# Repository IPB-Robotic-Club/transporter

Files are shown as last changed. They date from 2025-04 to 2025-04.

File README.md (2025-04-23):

# Transporter Robot  
This project features a two-wheeled transporter robot manually controlled via a PlayStation 3 wireless joystick over Bluetooth. Driven by an ESP32 running Arduino code, the robot includes a motorized gripper that can open, close, and move vertically to pick up and move objects.

## Transporter Robot Using ESP32 and PS3 Joystick

### 📘 Introduction  
The Transporter Robot project aims to build a two-wheeled robot capable of manually transporting objects in a controlled environment using a Bluetooth-connected PlayStation 3 joystick. The robot is powered by an ESP32 microcontroller running Arduino code. It features a dual-servo gripper system—one for lifting and one for gripping—and DC motors for directional movement.

### ⚙️ Key Features  
- **Manual Control:** Operated via a PS3 joystick connected through Bluetooth using MAC address pairing.  
- **Motorized Gripper System:**  
  - **MG90S Servo:** Controls the open/close movement of the gripper.  
  - **MG996R Servo:** Controls the vertical movement of the gripper for lifting.  
- **Two-Wheel Drive:** Two DC motors for movement—forward, backward, turning left/right.  
- **Stable Power Supply:** 3S LiPo battery regulated by LM2596 to 5V for safe component operation.  
- **Compact & Modular Design:** Frame and gripper parts are custom-designed and 3D printed.

### 🧰 Components Required  
- ESP32 Development Board  
- 2× DC Motors  
- 1× MG90S Servo Motor (gripper control)  
- 1× MG996R Servo Motor (gripper lift)  
- L298N Motor Driver Module  
- 3S LiPo Battery  
- LM2596 Step-down Voltage Regulator (12V to 5V)  
- PS3 Wireless Bluetooth Joystick  

### 📡 Bluetooth Pairing (PS3 to ESP32)  
1. Use a tool like **SixaxisPairTool** to check and change your PS3 joystick’s MAC address.  
2. In your Arduino code, call `PS3.begin("xx:xx:xx:xx:xx:xx")` with your **ESP32’s MAC address**.  
3. Upload code to ESP32.  
4. Press the **PS button** on the controller to connect.  
5. Successful connection: LED on PS3 stays solid.

### 🔌 Wiring Diagram  
Basic wiring includes -- diagram image will be soon:  
- DC motors connected to L298N motor driver  
- Servo motors connected to PWM pins on ESP32  
- Voltage from LiPo battery stepped down to 5V for ESP32 and servos  
- Bluetooth communication via onboard ESP32 module  
---
## Documentation

### Design Robot 
<p align="center">
  <a href="https://skfb.ly/pwtIJ">
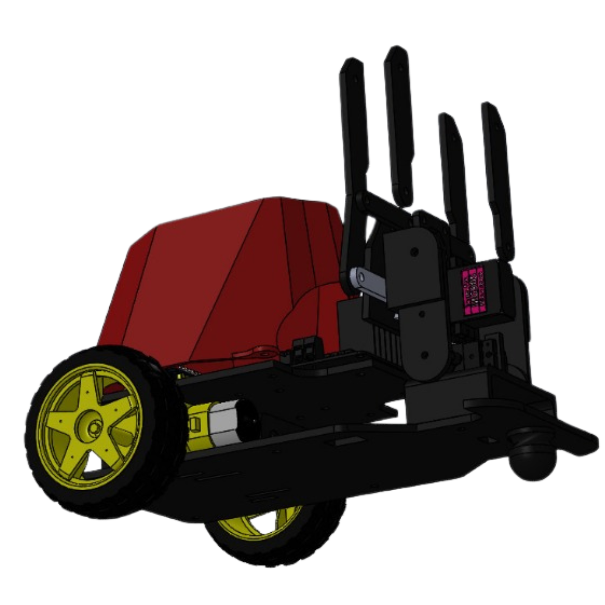
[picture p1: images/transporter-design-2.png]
Robot 3D Preview
    
  </a>
</p>

<p align="center">
  🔗 Click the image to view the interactive 3D model on Sketchfab.
</p>

### Final Build  
<div align="center">
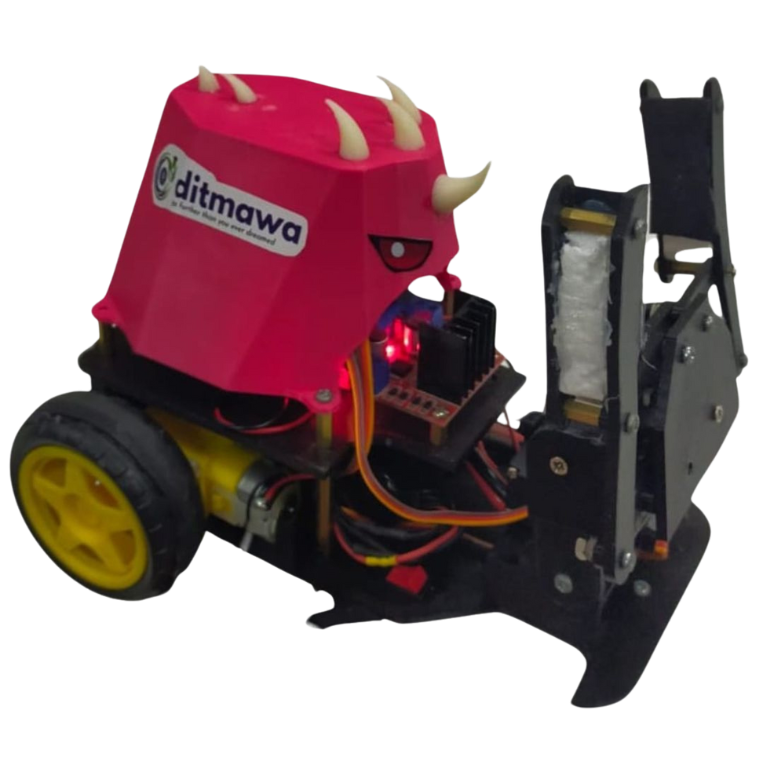
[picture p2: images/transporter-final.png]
Final Robot
  
</div>

## 🎉 Competition Success

Here’s our transporter robot that helped us bring home the prize at the Mechanical and Biosystems Fair 2024!

<div align="center">
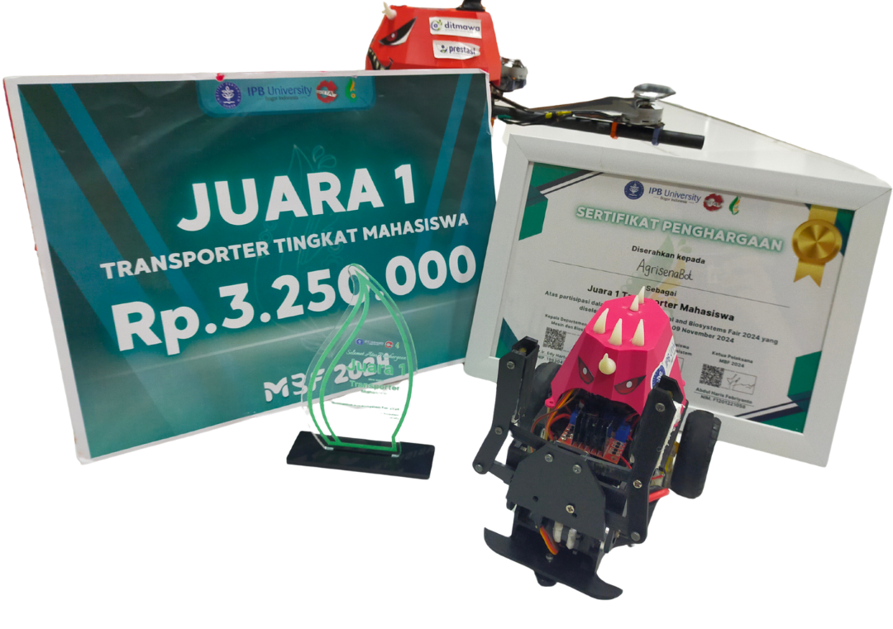
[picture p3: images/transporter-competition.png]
Winning Competition
  
</div>
```

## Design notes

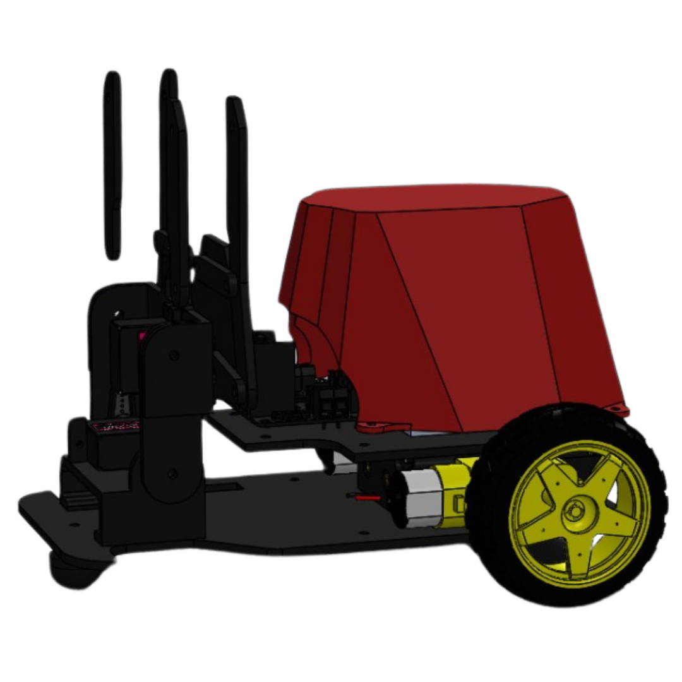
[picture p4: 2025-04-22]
images/transporter-design-1.png

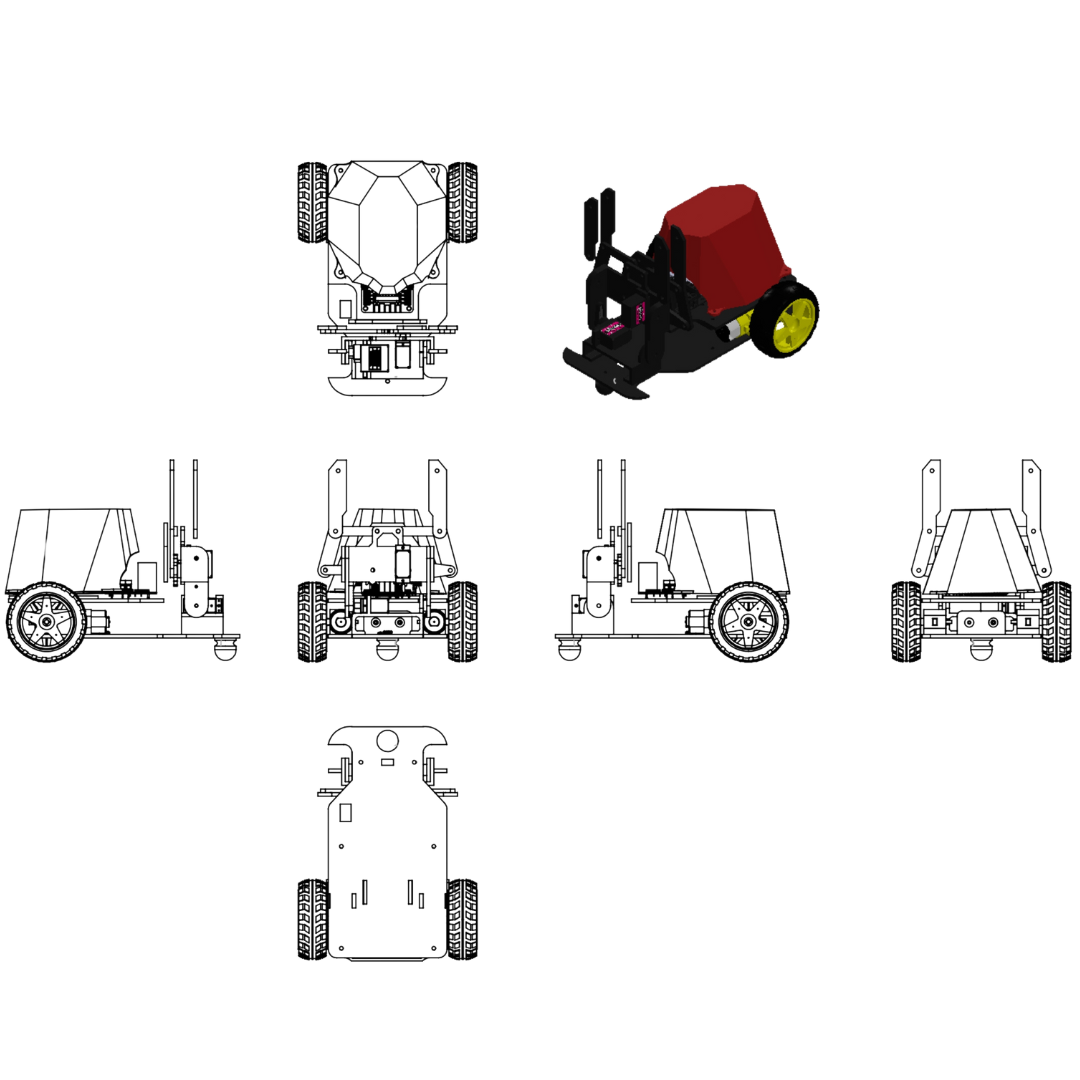
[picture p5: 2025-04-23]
images/transporter-design.png

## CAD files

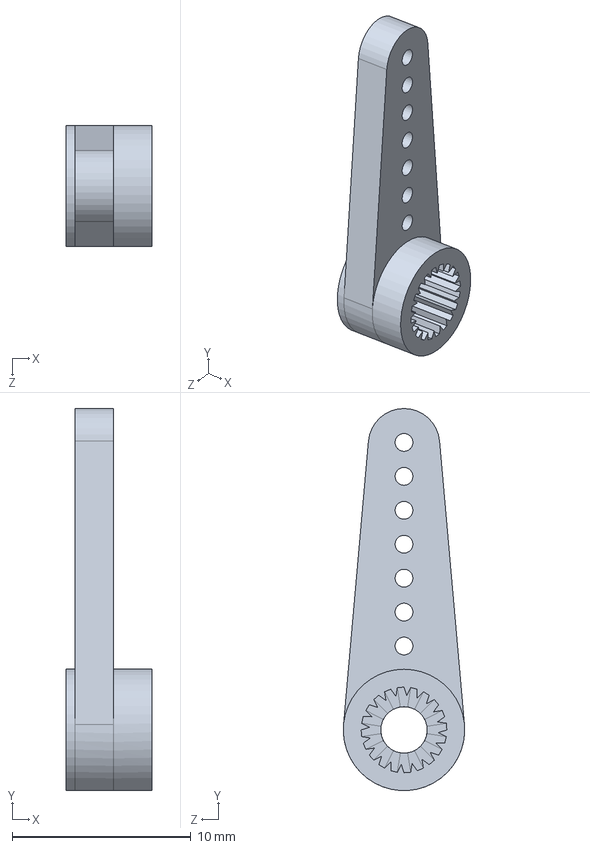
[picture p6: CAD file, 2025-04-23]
models/SLDPRT/MG90S_arm01.step.SLDPRT
4.80 x 21.4 x 6.80 mm

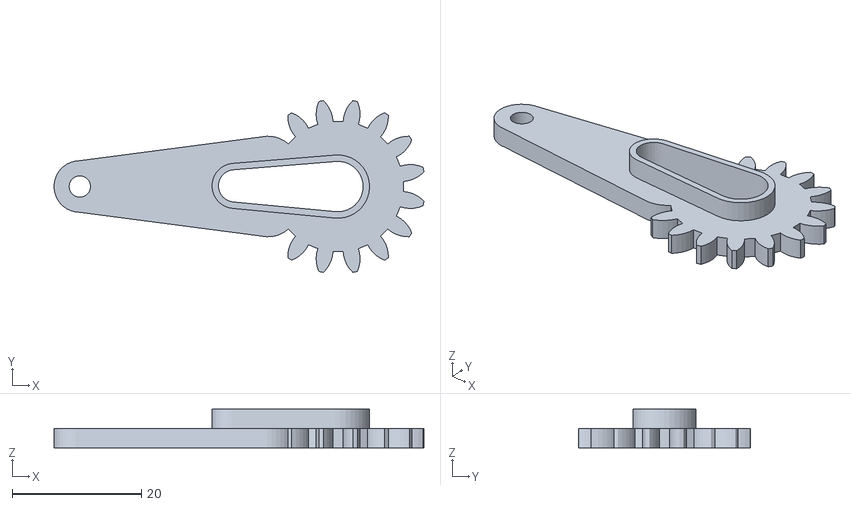
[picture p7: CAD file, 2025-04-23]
models/STL/Gear kiri 2.STL
57.3 x 26.6 x 6.00

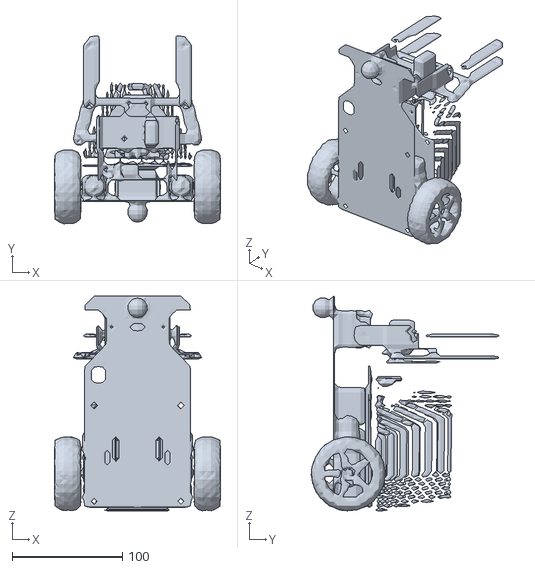
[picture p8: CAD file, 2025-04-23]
models/Transporter.STL.nanodlp-simplified.stl
151.1 x 170.4 x 195.2

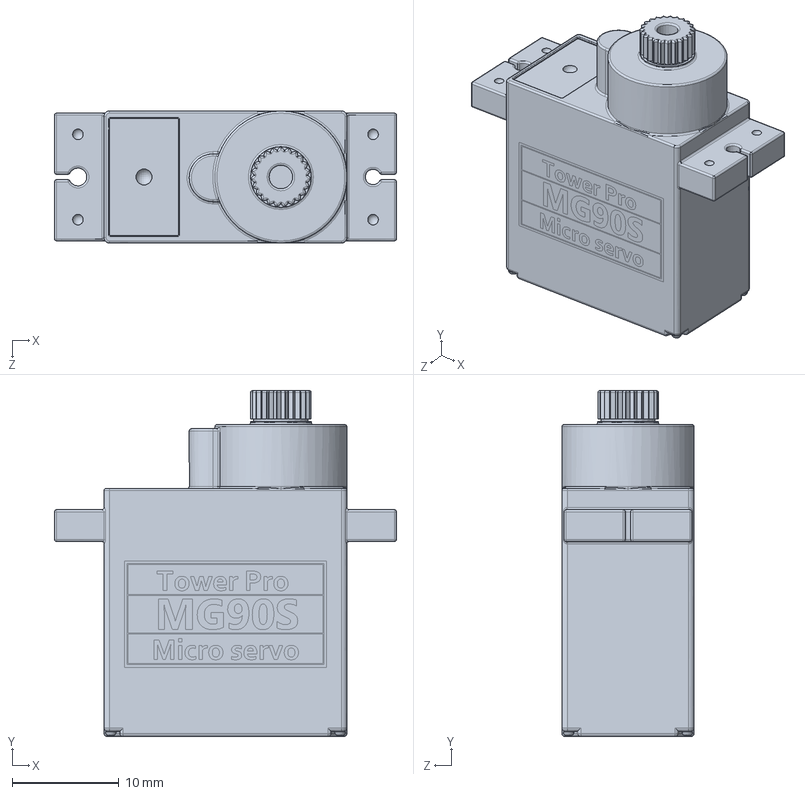
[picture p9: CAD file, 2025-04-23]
models/SLDPRT/Tower-Pro-MG90S.SLDPRT
32.1 x 32.5 x 12.4 mm

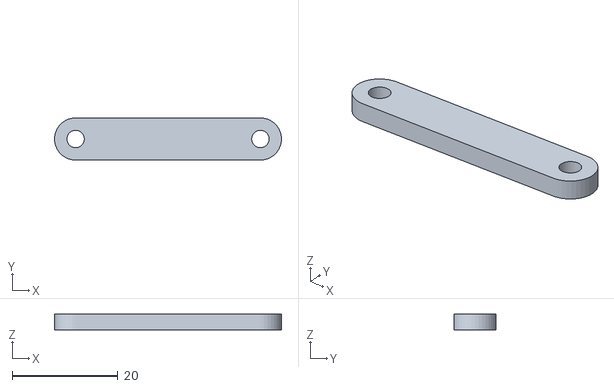
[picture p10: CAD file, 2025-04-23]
models/STL/lengan Gripper.STL
43.0 x 8.00 x 3.00

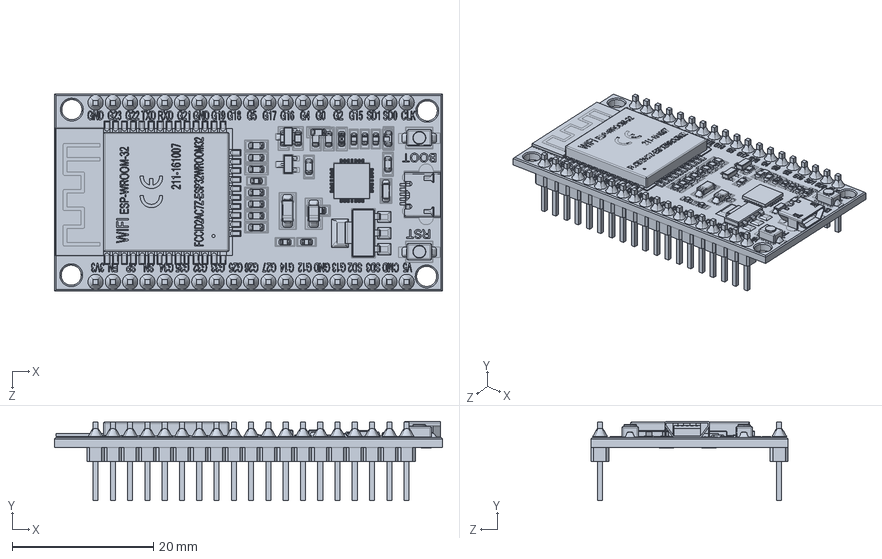
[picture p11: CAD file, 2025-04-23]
models/SLDPRT/ESP32-WROOM-32_03.stp.SLDPRT
55.0 x 11.2 x 27.9 mm

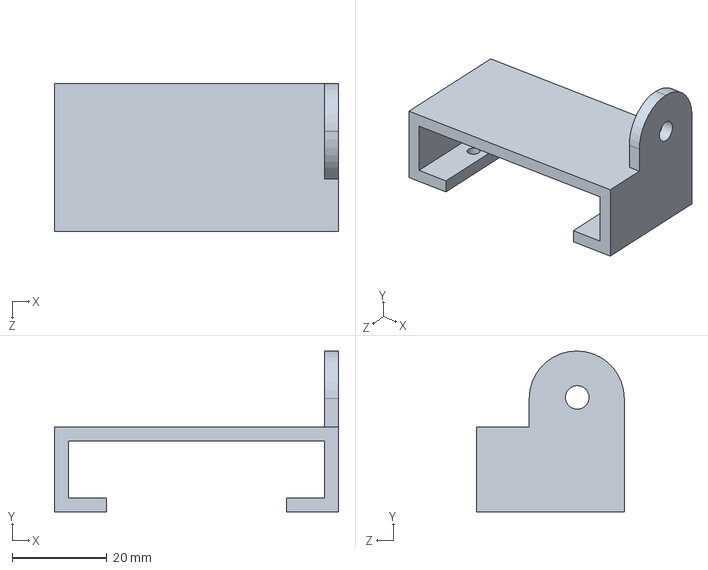
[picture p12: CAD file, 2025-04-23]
models/SLDPRT/Dudukan.SLDPRT
60.0 x 34.0 x 31.2 mm

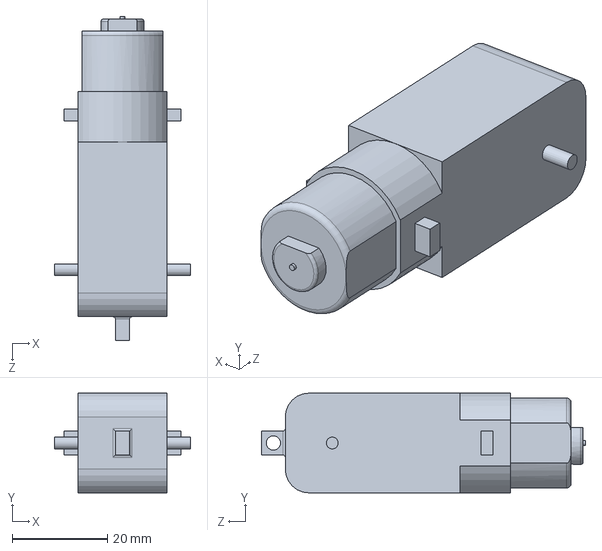
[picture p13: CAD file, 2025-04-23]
models/SLDPRT/Motor DC.SLDPRT
28.7 x 21.0 x 68.2 mm

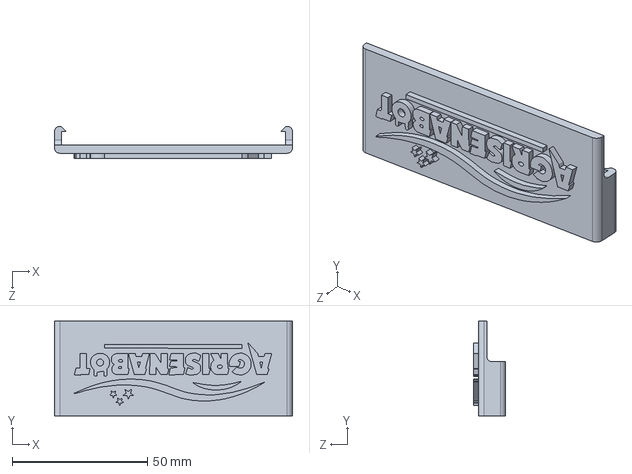
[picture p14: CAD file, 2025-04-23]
models/SLDPRT/Plat NAMA.SLDPRT
88.0 x 35.0 x 12.0 mm

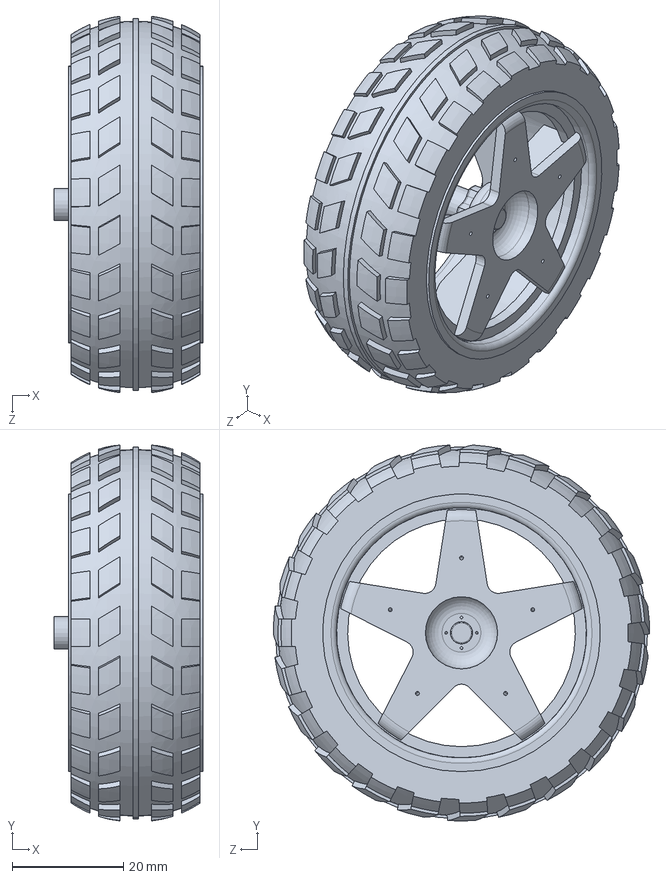
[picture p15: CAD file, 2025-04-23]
models/SLDPRT/Wheel.SLDPRT
26.8 x 67.7 x 67.8 mm

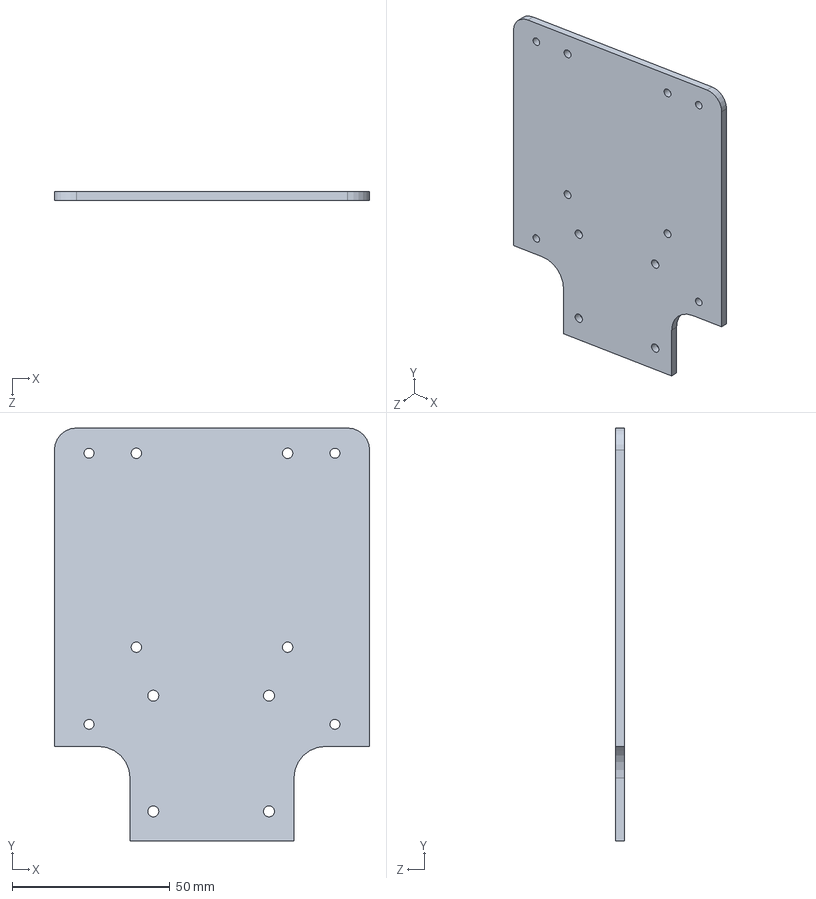
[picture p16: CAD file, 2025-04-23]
models/SLDPRT/Body Atas.SLDPRT
100.0 x 131.0 x 3.00 mm

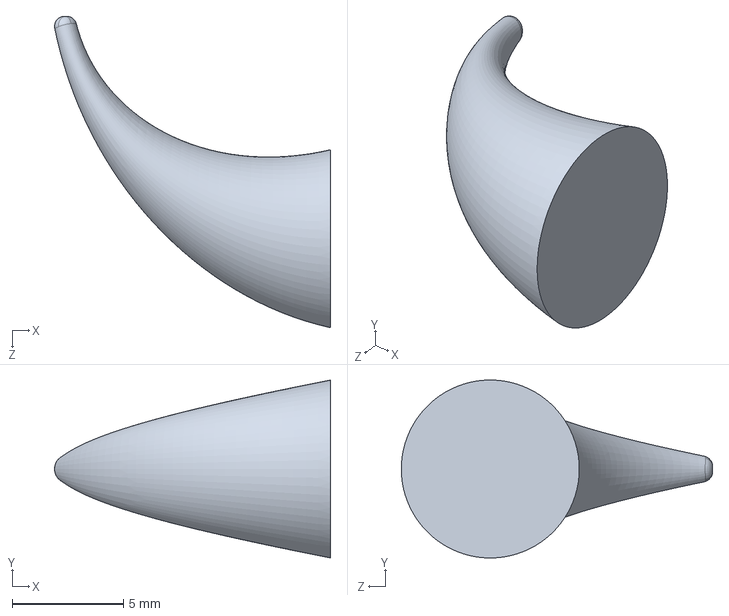
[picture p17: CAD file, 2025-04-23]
models/SLDPRT/Tanduk SLDPRT.SLDPRT
12.4 x 8.00 x 14.0 mm

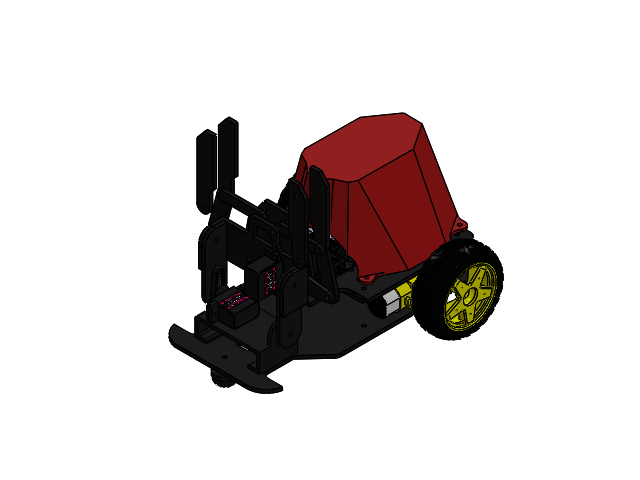
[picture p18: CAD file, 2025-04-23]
models/Transporter.SLDASM
Tower-Pro-MG90S x 2
MG90S_arm01.step x 2
Motor DC x 2
Wheel x 2
Dudukan
Gear Hand kiri
Gear Hand kanan
L298N Driver.STEP
2x Li-Ion 3,7 V Battery Pack
ESP32-WROOM-32_03.stp
Dudukan Grip
Gear kiri
Part 1 - Gripper x 2
Body Atas
Gripper Hand atas x 2
Gear Kanan
Gear Hand Bawah x 2
Ban Depan
Dudukan ESP
Penutup Gear
Kubah 2

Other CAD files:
models/SLDPRT/Penutup Gear.SLDPRT
models/SLDPRT/Kubah 2.SLDPRT
models/SLDPRT/Dudukan ESP.SLDPRT
models/SLDPRT/Gear Kanan.SLDPRT
models/SLDPRT/Gear kiri.SLDPRT
models/SLDPRT/Ban Depan.SLDPRT
models/SLDPRT/Body.SLDPRT
models/SLDPRT/Dudukan Grip.SLDPRT
models/SLDPRT/Gear Hand Bawah.SLDPRT
models/SLDPRT/Gear Hand kanan.SLDPRT
models/SLDPRT/Gear Hand kiri.SLDPRT
models/SLDPRT/Gripper Hand atas.SLDPRT
models/SLDPRT/Kubah.SLDPRT
models/SLDPRT/L298N Driver.STEP.SLDPRT
models/SLDPRT/Lippo 3s dimention.SLDPRT
models/SLDPRT/Part 1 - Gripper.SLDPRT
models/SLDPRT/Part3.SLDPRT
models/SLDPRT/Part6.SLDPRT
models/STL/Ban Depan.STL
models/STL/Body Atas.STL
models/STL/Body.STL
models/STL/Dudukan Grip.STL
models/STL/Dudukan.STL
models/STL/Gear Hand Bawah.STL
models/STL/Gear Hand kanan.STL
models/STL/Gear Hand kiri.STL
models/STL/Gear Kanan.STL
models/STL/Gear kiri.STL
models/STL/Gripper Hand atas.STL
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

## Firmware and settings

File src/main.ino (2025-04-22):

#include <ESP32Servo.h>
#include <Ps3Controller.h>

// Motor pins
int enableRightMotor = 33;
int rightMotorPin1 = 26;
int rightMotorPin2 = 25;
int enableLeftMotor = 12;
int leftMotorPin1 = 14;
int leftMotorPin2 = 27;

// Servo pins
const int servoPin1 = 19; // Gripper servo
const int servoPin2 = 5;  // Lift servo
Servo servo1;
Servo servo2;

bool gripperOpen = false; // Gripper status (open or closed)
bool liftUp = false;      // Lift status (up or down)

// Servo positions and limits
int gripperPosition = 55; // Initial gripper position
int liftPosition = 45;    // Initial lift position
const int GRIPPER_OPEN = 115;
const int GRIPPER_CLOSED = 55;
const int LIFT_UP = 45;
const int LIFT_DOWN = 145;
const int SERVO_DELAY = 15;
const int LIFT_DOWN1 = 125;

const int slowSpeed = 150; // Slow speed for motors

// Motor settings
#define MAX_MOTOR_SPEED 255
const int PWMFreq = 1000;
const int PWMResolution = 8;
const int rightMotorPWMSpeedChannel = 4;
const int leftMotorPWMSpeedChannel = 5;
const float STICK_THRESHOLD = 0.1;

// Additional variables for enhanced control
int currentSpeed = MAX_MOTOR_SPEED; // Variable speed control
bool precisionMode = false;         // Precision mode flag
int battery = 0;                    // Battery level tracking
unsigned long lastMoveTime = 0;     // For movement timeout
const int MOVE_TIMEOUT = 400;       // Movement timeout in ms

void handleMovement()
{
    float x = (float)Ps3.data.analog.stick.lx / 128.0;
    float y = -(float)Ps3.data.analog.stick.ly / 128.0;

    // Check if the stick is in a neutral position (close to 0)
    if (abs(x) < STICK_THRESHOLD && abs(y) < STICK_THRESHOLD)
    {
        // Stick released, stop the motors
        rotateMotor(0, 0);
        return;
    }

    // Convert to tank drive
    float leftMotorSpeed = y + x;
    float rightMotorSpeed = y - x;

    // Normalize speeds
    float maxSpeed = max(abs(leftMotorSpeed), abs(rightMotorSpeed));
    if (maxSpeed > 1.0)
    {
        leftMotorSpeed /= maxSpeed;
        rightMotorSpeed /= maxSpeed;
    }

    // Apply current speed setting
    rotateMotor(rightMotorSpeed * currentSpeed, leftMotorSpeed * currentSpeed);
}

void notify()
{

    handleMovement();

    // Gripper controls
    if (Ps3.event.button_down.left)
    {
        moveServoSlowly(servo1, gripperPosition, GRIPPER_CLOSED, SERVO_DELAY);
        gripperPosition = GRIPPER_CLOSED;
    }
    if (Ps3.event.button_down.right)
    {
        servo1.write(GRIPPER_OPEN);
        gripperPosition = GRIPPER_OPEN;
    }

    // Lift controls
    if (Ps3.event.button_down.up)
    {
        moveServoSlowly(servo2, liftPosition, LIFT_UP, SERVO_DELAY);
        liftPosition = LIFT_UP;
    }
    if (Ps3.event.button_down.down)
    {
        moveServoSlowly(servo2, liftPosition, LIFT_DOWN, SERVO_DELAY);
        liftPosition = LIFT_DOWN;
    }

    if (Ps3.event.button_down.cross)
    {
        if (currentSpeed == slowSpeed)
        {
            // If the current speed is slow, set to maximum
            currentSpeed = MAX_MOTOR_SPEED;
            Serial.println("Speed set to maximum");
        }
        else
        {
            // If the current speed is maximum, set to slow
            currentSpeed = slowSpeed;
            Serial.println("Speed set to slow");
        }
    }
    if (Ps3.event.button_down.square)
    {
        moveServoSlowly(servo2, liftPosition, LIFT_DOWN, SERVO_DELAY);
        liftPosition = LIFT_DOWN;
        servo1.write(GRIPPER_OPEN);
        gripperPosition = GRIPPER_OPEN;
    }
    if (Ps3.event.button_down.triangle)
    {
        moveServoSlowly(servo1, gripperPosition, GRIPPER_CLOSED, SERVO_DELAY);
        gripperPosition = GRIPPER_CLOSED;
        moveServoSlowly(servo2, liftPosition, LIFT_UP, SERVO_DELAY);
        liftPosition = LIFT_UP;
    }
    // Rotation
    if (Ps3.event.button_down.circle)
    {
        rotateMotor(MAX_MOTOR_SPEED, -MAX_MOTOR_SPEED);
    }

    if (Ps3.event.button_down.l1)
    {
        Serial.println("Started pressing the left trigger button");
        toggleGripper();
    }
    if (Ps3.event.button_down.r1)
    {
        Serial.println("Started pressing the right trigger button");
        toggleLift();
    }

    if (Ps3.event.button_down.l2)
    {
        precisionMode = !precisionMode;
        Serial.printf("Precision mode: %s\n", precisionMode ? "ON" : "OFF");
    }

    // Precision mode
    if (Ps3.event.button_down.r2)
    {
        Serial.println("Started pressing the right trigger button to 5 cm");
        toggleLift1();
    }

    // Battery monitoring
    if (battery != Ps3.data.status.battery)
    {
        battery = Ps3.data.status.battery;
        Serial.print("Battery: ");
        if (battery == ps3_status_battery_charging)
            Serial.println("Charging");
        else if (battery == ps3_status_battery_full)
            Serial.println("Full");
        else if (battery == ps3_status_battery_high)
            Serial.println("High");
        else if (battery == ps3_status_battery_low)
            Serial.println("Low");
        else if (battery == ps3_status_battery_dying)
            Serial.println("Critical");
        else if (battery == ps3_status_battery_shutdown)
            Serial.println("Shutting down");
    }
}

void stopMotors()
{
    digitalWrite(leftMotorPin1, 0);
    digitalWrite(leftMotorPin2, 0);
    digitalWrite(rightMotorPin1, 0);
    digitalWrite(rightMotorPin2, 0);
}

// Function to toggle the gripper (open and close the gripper)
void toggleGripper()
{
    if (!gripperOpen)
    {
        moveServoSlowly(servo1, gripperPosition, GRIPPER_OPEN, SERVO_DELAY);
        gripperOpen = true;
    }
    else
    {
        moveServoSlowly(servo1, gripperPosition, GRIPPER_CLOSED, SERVO_DELAY);
        gripperOpen = false;
    }
}

// Function to toggle the lift (raise and lower the lift)
void toggleLift1()
{
    if (!liftUp)
    {
        moveServoSlowly(servo2, liftPosition, LIFT_UP, SERVO_DELAY);
        liftUp = true;
    }
    else
    {
        moveServoSlowly(servo2, liftPosition, LIFT_DOWN1, SERVO_DELAY);
        liftUp = false;
    }
}

// Function to toggle the lift (raise and lower the lift)
void toggleLift()
{
    if (!liftUp)
    {
        moveServoSlowly(servo2, liftPosition, LIFT_UP, SERVO_DELAY);
        liftUp = true;
    }
    else
    {
        moveServoSlowly(servo2, liftPosition, LIFT_DOWN, SERVO_DELAY);
        liftUp = false;
    }
}

void rotateMotor(int rightMotorSpeed, int leftMotorSpeed)
{
    // Apply precision mode if enabled
    if (precisionMode)
    {
        rightMotorSpeed = rightMotorSpeed * 0.5;
        leftMotorSpeed = leftMotorSpeed * 0.5;
    }

    // Right motor direction
    if (rightMotorSpeed < 0)
    {
        digitalWrite(rightMotorPin1, LOW);
        digitalWrite(rightMotorPin2, HIGH);
    }
    else if (rightMotorSpeed > 0)
    {
        digitalWrite(rightMotorPin1, HIGH);
        digitalWrite(rightMotorPin2, LOW);
    }
    else
    {
        digitalWrite(rightMotorPin1, LOW);
        digitalWrite(rightMotorPin2, LOW);
    }

    // Left motor direction
    if (leftMotorSpeed < 0)
    {
        digitalWrite(leftMotorPin1, LOW);
        digitalWrite(leftMotorPin2, HIGH);
    }
    else if (leftMotorSpeed > 0)
    {
        digitalWrite(leftMotorPin1, HIGH);
        digitalWrite(leftMotorPin2, LOW);
    }
    else
    {
        digitalWrite(leftMotorPin1, LOW);
        digitalWrite(leftMotorPin2, LOW);
    }

    // Set motor speeds
    ledcWrite(rightMotorPWMSpeedChannel, abs(rightMotorSpeed));
    ledcWrite(leftMotorPWMSpeedChannel, abs(leftMotorSpeed));
}

void setUpPinModes()
{
    pinMode(enableRightMotor, OUTPUT);
    pinMode(rightMotorPin1, OUTPUT);
    pinMode(rightMotorPin2, OUTPUT);
    pinMode(enableLeftMotor, OUTPUT);
    pinMode(leftMotorPin1, OUTPUT);
    pinMode(leftMotorPin2, OUTPUT);

    ledcSetup(rightMotorPWMSpeedChannel, PWMFreq, PWMResolution);
    ledcSetup(leftMotorPWMSpeedChannel, PWMFreq, PWMResolution);
    ledcAttachPin(enableRightMotor, rightMotorPWMSpeedChannel);
    ledcAttachPin(enableLeftMotor, leftMotorPWMSpeedChannel);

    rotateMotor(0, 0);
}

void moveServoSlowly(Servo &servo, int startPos, int endPos, int stepDelay)
{
    if (startPos < endPos)
    {
        for (int pos = startPos; pos <= endPos; pos += 4)
        {
            servo.write(pos);
            delay(stepDelay);
        }
    }
    else
    {
        for (int pos = startPos; pos >= endPos; pos -= 4)
        {
            servo.write(pos);
            delay(stepDelay);
        }
    }
}

void onConnect()
{
    Serial.println("PS3 Controller Connected.");
    currentSpeed = MAX_MOTOR_SPEED;
    precisionMode = false;
}

void setup()
{
    Serial.begin(115200);
    setUpPinModes();

    // Servo setup
    ESP32PWM::allocateTimer(0);
    ESP32PWM::allocateTimer(1);
    ESP32PWM::allocateTimer(2);
    ESP32PWM::allocateTimer(3);

    servo1.setPeriodHertz(50);
    servo2.setPeriodHertz(50);
    servo1.attach(servoPin1, 500, 2400);
    servo2.attach(servoPin2, 500, 2400);

    servo1.write(gripperPosition);
    servo2.write(liftPosition);

    // PS3 Controller setup
    Ps3.attach(notify);
    Ps3.attachOnConnect(onConnect);
    Ps3.begin("c0:5d:89:b1:55:02"); // Replace with your ESP32's MAC address

    Serial.println("Setup completed. Waiting for PS3 controller connection...");
}

void loop()
{
    if (!Ps3.isConnected())
    {
        rotateMotor(0, 0); // Stop motors if controller disconnected
        return;
    }

    // Movement timeout - stop motors if no input received
    if (millis() - lastMoveTime > MOVE_TIMEOUT)
    {
        rotateMotor(0, 0);
    }

    delay(20); // Small delay to prevent overwhelming the system
}

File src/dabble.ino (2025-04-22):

/*
  This code is designed for use with the Dabble mobile application by STEMpedia, Arduino ESP Bluetooth - Dabble
  Dabble is a Bluetooth-based control app that allows users to send commands from a smartphone to Arduino-based robots.
  Make sure to install the Dabble library from STEMpedia and pair your Bluetooth module (like HC-05 or HC-06) with your phone.
*/


#define CUSTOM_SETTINGS
#define INCLUDE_GAMEPAD_MODULE
#include <DabbleESP32.h>
#include <ESP32Servo.h>

// Right motor
int enableRightMotor = 12;
int rightMotorPin1 = 14;
int rightMotorPin2 = 27;

// Left motor
int enableLeftMotor = 33;
int leftMotorPin1 = 26;
int leftMotorPin2 = 25;

// Gripper servos
const int servoPin1 = 15; // Gripper servo
const int servoPin2 = 5;  // Lift servo
Servo servo1;
Servo servo2;

bool precisionMode = false; // Precision mode flag

// Servo positions and limits
int position1 = 130; // Initial gripper position
int position2 = 30;  // Initial lift position
const int GRIPPER_OPEN = 130;
const int GRIPPER_CLOSED = 30;
const int LIFT_UP = 30;
const int LIFT_DOWN = 135;
const int LIFT_DOWN1 = 120;
const int SERVO_DELAY = 15;
int UP = 30;
int BOTTOM = 135;

// Motor settings
#define MAX_MOTOR_SPEED 255
const int PWMFreq = 1000;
const int PWMResolution = 8;
const int rightMotorPWMSpeedChannel = 4;
const int leftMotorPWMSpeedChannel = 5;

// Joystick deadzone threshold
const float JOYSTICK_THRESHOLD = 2.0;

void rotateMotor(int rightMotorSpeed, int leftMotorSpeed)
{
    if (precisionMode)
    {
        rightMotorSpeed = rightMotorSpeed * 0.7;
        leftMotorSpeed = leftMotorSpeed * 0.7;
    }

    // Right motor direction
    if (rightMotorSpeed < 0)
    {
        digitalWrite(rightMotorPin1, LOW);
        digitalWrite(rightMotorPin2, HIGH);
    }
    else if (rightMotorSpeed > 0)
    {
        digitalWrite(rightMotorPin1, HIGH);
        digitalWrite(rightMotorPin2, LOW);
    }
    else
    {
        digitalWrite(rightMotorPin1, LOW);
        digitalWrite(rightMotorPin2, LOW);
    }

    // Left motor direction
    if (leftMotorSpeed < 0)
    {
        digitalWrite(leftMotorPin1, LOW);
        digitalWrite(leftMotorPin2, HIGH);
    }
    else if (leftMotorSpeed > 0)
    {
        digitalWrite(leftMotorPin1, HIGH);
        digitalWrite(leftMotorPin2, LOW);
    }
    else
    {
        digitalWrite(leftMotorPin1, LOW);
        digitalWrite(leftMotorPin2, LOW);
    }

    ledcWrite(rightMotorPWMSpeedChannel, abs(rightMotorSpeed));
    ledcWrite(leftMotorPWMSpeedChannel, abs(leftMotorSpeed));
}

void moveServoSlowly(Servo &servo, int startPos, int endPos, int stepDelay)
{
    if (startPos < endPos)
    {
        for (int pos = startPos; pos <= endPos; pos += 4)
        {
            servo.write(pos);
            delay(stepDelay);
        }
    }
    else
    {
        for (int pos = startPos; pos >= endPos; pos -= 4)
        {
            servo.write(pos);
            delay(stepDelay);
        }
    }
}

void setUpPinModes()
{
    pinMode(enableRightMotor, OUTPUT);
    pinMode(rightMotorPin1, OUTPUT);
    pinMode(rightMotorPin2, OUTPUT);

    pinMode(enableLeftMotor, OUTPUT);
    pinMode(leftMotorPin1, OUTPUT);
    pinMode(leftMotorPin2, OUTPUT);

    ledcSetup(rightMotorPWMSpeedChannel, PWMFreq, PWMResolution);
    ledcSetup(leftMotorPWMSpeedChannel, PWMFreq, PWMResolution);
    ledcAttachPin(enableRightMotor, rightMotorPWMSpeedChannel);
    ledcAttachPin(enableLeftMotor, leftMotorPWMSpeedChannel);

    rotateMotor(0, 0);
}

void setup()
{
    Serial.begin(115200);
    setUpPinModes();
    Dabble.begin("GalaxyA35");

    ESP32PWM::allocateTimer(0);
    ESP32PWM::allocateTimer(1);
    ESP32PWM::allocateTimer(2);
    ESP32PWM::allocateTimer(3);

    servo1.setPeriodHertz(50);
    servo2.setPeriodHertz(50);

    servo1.attach(servoPin1, 500, 2400);
    servo2.attach(servoPin2, 500, 2400);

    servo1.write(position1);
    servo2.write(position2);
}

void loop()
{
    int rightMotorSpeed = 0;
    int leftMotorSpeed = 0;

    Dabble.processInput();

    // Joystick control
    float xAxis = GamePad.getXaxisData();
    float yAxis = GamePad.getYaxisData();

    // Calculate motor speeds based on joystick position
    if (abs(xAxis) > JOYSTICK_THRESHOLD || abs(yAxis) > JOYSTICK_THRESHOLD)
    {
        float forwardSpeedMultiplier = MAX_MOTOR_SPEED / 7.0;      
        float turnSpeedMultiplier = (MAX_MOTOR_SPEED / 7.0) * 0.5; //for turning

        // Separate calculations for forward/backward and turning
        float forwardComponent = yAxis * forwardSpeedMultiplier;
        float turnComponent = xAxis * turnSpeedMultiplier;

        // Combine components
        rightMotorSpeed = forwardComponent - turnComponent;
        leftMotorSpeed = forwardComponent + turnComponent;

        // Ensure speeds don't exceed limits
        rightMotorSpeed = constrain(rightMotorSpeed, -MAX_MOTOR_SPEED, MAX_MOTOR_SPEED);
        leftMotorSpeed = constrain(leftMotorSpeed, -MAX_MOTOR_SPEED, MAX_MOTOR_SPEED);
    }

    // Button controls (original)
    if (GamePad.isUpPressed())
    {
        rightMotorSpeed = MAX_MOTOR_SPEED;
        leftMotorSpeed = MAX_MOTOR_SPEED;
    }
    if (GamePad.isDownPressed())
    {
        rightMotorSpeed = -MAX_MOTOR_SPEED;
        leftMotorSpeed = -MAX_MOTOR_SPEED;
    }
    if (GamePad.isLeftPressed())
    {
        rightMotorSpeed = MAX_MOTOR_SPEED;
        leftMotorSpeed = -MAX_MOTOR_SPEED;
    }
    if (GamePad.isRightPressed())
    {
        rightMotorSpeed = -MAX_MOTOR_SPEED;
        leftMotorSpeed = MAX_MOTOR_SPEED;
    }

    // Gripper controls
    if (GamePad.isSquarePressed())
    {
        servo1.write(GRIPPER_OPEN);
        position1 = GRIPPER_OPEN;
        Serial.println("Gripper opened instantly");
    }

    if (GamePad.isCirclePressed())
    {
        moveServoSlowly(servo1, position1, GRIPPER_CLOSED, SERVO_DELAY);
        position1 = GRIPPER_CLOSED;
    }

    if (GamePad.isTrianglePressed())
    {
        servo2.write(LIFT_UP);
        position2 = LIFT_UP;
        Serial.println("Gripper lifted instantly");
    }

    if (GamePad.isCrossPressed())
    {
        moveServoSlowly(servo2, position2, LIFT_DOWN, SERVO_DELAY);
        position2 = LIFT_DOWN;
    }

    if (GamePad.isStartPressed())
    {
        moveServoSlowly(servo1, position1, GRIPPER_CLOSED, SERVO_DELAY);
        position1 = GRIPPER_CLOSED;
        servo2.write(LIFT_UP);
        position2 = LIFT_UP;
        Serial.println("Gripper lifted instantly");
    }

    if (GamePad.isSelectPressed())
    {
        precisionMode = !precisionMode;
        Serial.printf("Precision mode: %s\n", precisionMode ? "ON" : "OFF");
    }

    // Debug joystick values
    Serial.print("X: ");
    Serial.print(xAxis);
    Serial.print("\tY: ");
    Serial.print(yAxis);
    Serial.print("\tRight Motor: ");
    Serial.print(rightMotorSpeed);
    Serial.print("\tLeft Motor: ");
    Serial.println(leftMotorSpeed);

    rotateMotor(rightMotorSpeed, leftMotorSpeed);
}

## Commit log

2025-04-22 Create folder for models CAD
2025-04-23 Add design files
    [Ban Depan.SLDPRT, Ban Depan.STL, Body Atas.SLDPRT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]
2025-04-23 Track STL and STEP files using Git LFS
2025-04-23 Add file stl
2025-05-03 Create ps3-motor
2025-05-03 Update ps3-motor
2025-05-03 Create custom-motor
2025-05-03 Create cek-derajat-servo
